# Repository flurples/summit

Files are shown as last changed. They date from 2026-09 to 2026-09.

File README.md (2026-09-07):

# summit
a gummy o-ring mount, mx compatible, symmetric hhkb

front-cover
build video: https://youtu.be/qhuydgdiscI

## specifications
- bakeneko/unikorn style gummy o-ring mount with hhkb exclusive design
- typing angle: 7.5°
- ekh: 23.6 mm
- supported layout:
layout-options

## you will need
- 1x case
- 1x weight-internal
- 1x weight-external
- 1x plate
- 1x pcb
- 1x unified daughterboard s1 (be sure to get a double sided molex cable)
- 1x gummy o-ring (I really like graveshift o-rings but any o-rings designed to work with a 60% will do)
- 6x m3 x 6mm flat head hex screws
- 4x 7.9mm diameter rubber feet (I use 3m sj5302)

## build notes
- all holes should be tapped with m3 threads.
- weight-internal and weight-external are designed to be cnc'd or laser cut from 1.6mm sheet metal, which can potentially save on manufacturing costs compared to typical 3d cnc'd weights.
- as with any gummy o-ring mount, plateless is not recommended.

## disclaimer
I do not sell any products, and I am not affiliated with any vendors who claim to sell my designs. if you choose to support these vendors, I am not responsible for any issues you may encounter with them.

## renders
frontv5
bottomv5brass
bottomv5ss
explodedv1-centered

## gallery
note: images are of an older version of the summit, with a different internal weight design
front-pom
front-striker

back
back-closeup
inside
inside-closeup
usbc

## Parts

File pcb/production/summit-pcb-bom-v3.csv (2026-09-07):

Comment | Designator | Footprint | LCSC Part Number
0.1uF | C1,C2,C3 | Capacitor_SMD:C_0805_2012Metric | C1711
10uF | C4 | Capacitor_SMD:C_0805_2012Metric | C17024
22pF | C5,C6 | Capacitor_SMD:C_0805_2012Metric | C1804
1uF | C7 | Capacitor_SMD:C_0805_2012Metric | C28323
SOD-123 | D1,D2,D3,D4,D5,D6,D7,D8,D9,D10,D11,D12,D13,D14,D15,D16,D17,D18,D19,D20,D21,D22,D23,D24,D25,D26,D27,D28,D29,D30,D31,D32,D33,D34,D35,D36,D37,D38,D39,D40,D41,D42,D43,D44,D45,D46,D47,D48,D49,D50,D51,D52,D53,D54,D55,D56,D57,D58,D59,D60,D61,D62 | Diode_SMD:D_SOD-123 | C2099
500mA | F1 | Fuse:Fuse_1206_3216Metric | C369160
Conn_01x04 | J1 | Connector_Molex:Molex_Pico-EZmate_78171-0004_1x04-1MP_P1.20mm_Vertical | C2829871
22 | R1,R2 | Resistor_SMD:R_0805_2012Metric | C17561
10k | R3,R4 | Resistor_SMD:R_0805_2012Metric | C17414
SW_Push | SW1 | random-keyboard-parts:SKQG-1155865 | C5140332
ATmega32U4-MU | U1 | Package_DFN_QFN:QFN-44-1EP_7x7mm_P0.5mm_EP5.2x5.2mm | C112161
16MHz | Y1 | Crystal:Crystal_SMD_3225-4Pin_3.2x2.5mm | C13738

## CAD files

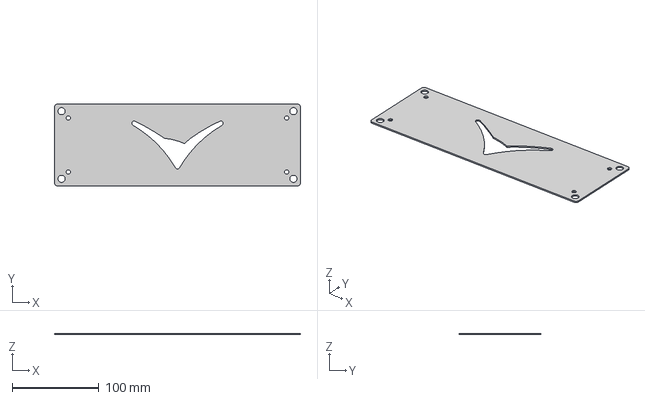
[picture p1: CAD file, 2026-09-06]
case/step/summit-weight-external.step
284.0 x 94.4 x 1.60 mm

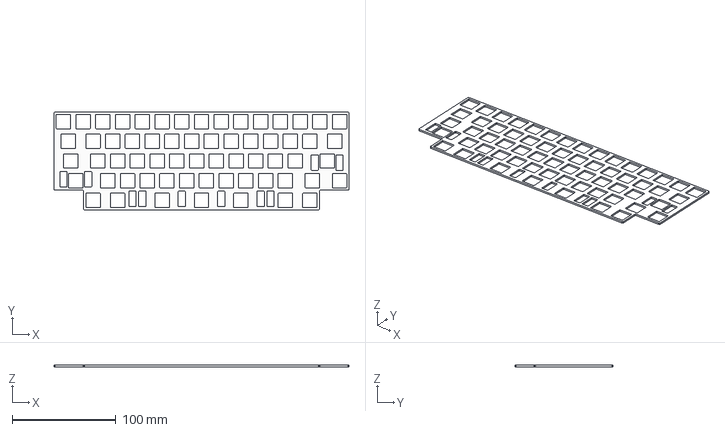
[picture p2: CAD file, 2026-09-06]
plate/step/summit-plate.step
285.0 x 94.4 x 1.60 mm

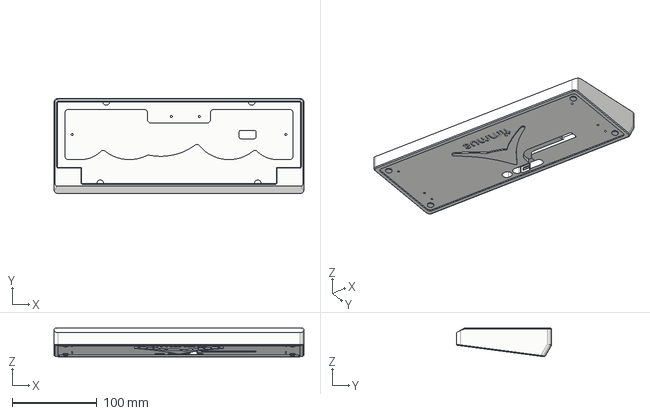
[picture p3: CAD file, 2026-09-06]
case/step/summit-case.step
294.8 x 112.2 x 33.6 mm

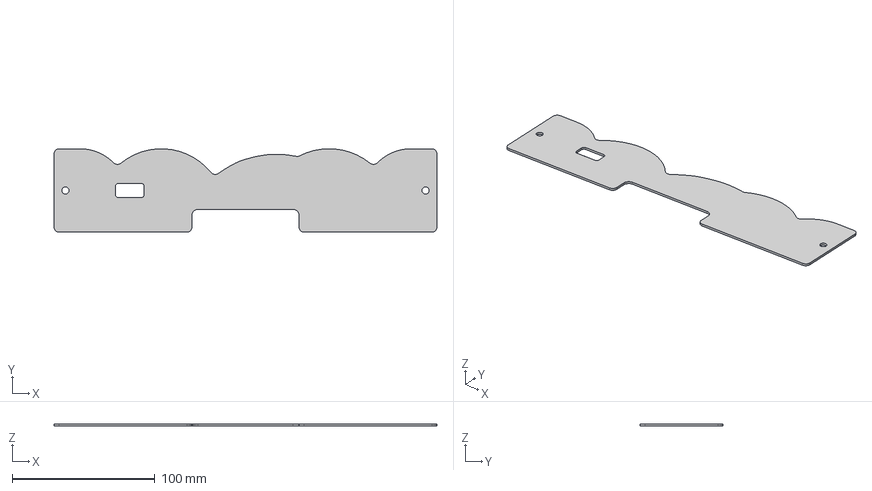
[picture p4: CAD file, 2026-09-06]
case/step/summit-weight-internal.step
268.0 x 58.4 x 1.60 mm

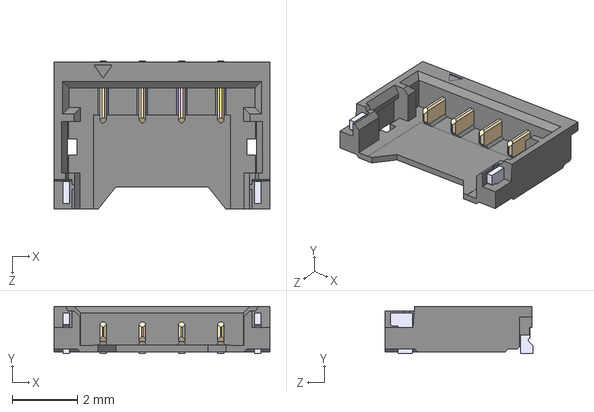
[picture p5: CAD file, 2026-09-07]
pcb/extra/0781710004.step
6.60 x 1.45 x 4.53 mm

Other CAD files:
case/dxf/summit-weight-external.dxf
case/dxf/summit-weight-internal.dxf
plate/dxf/summit-plate.dxf

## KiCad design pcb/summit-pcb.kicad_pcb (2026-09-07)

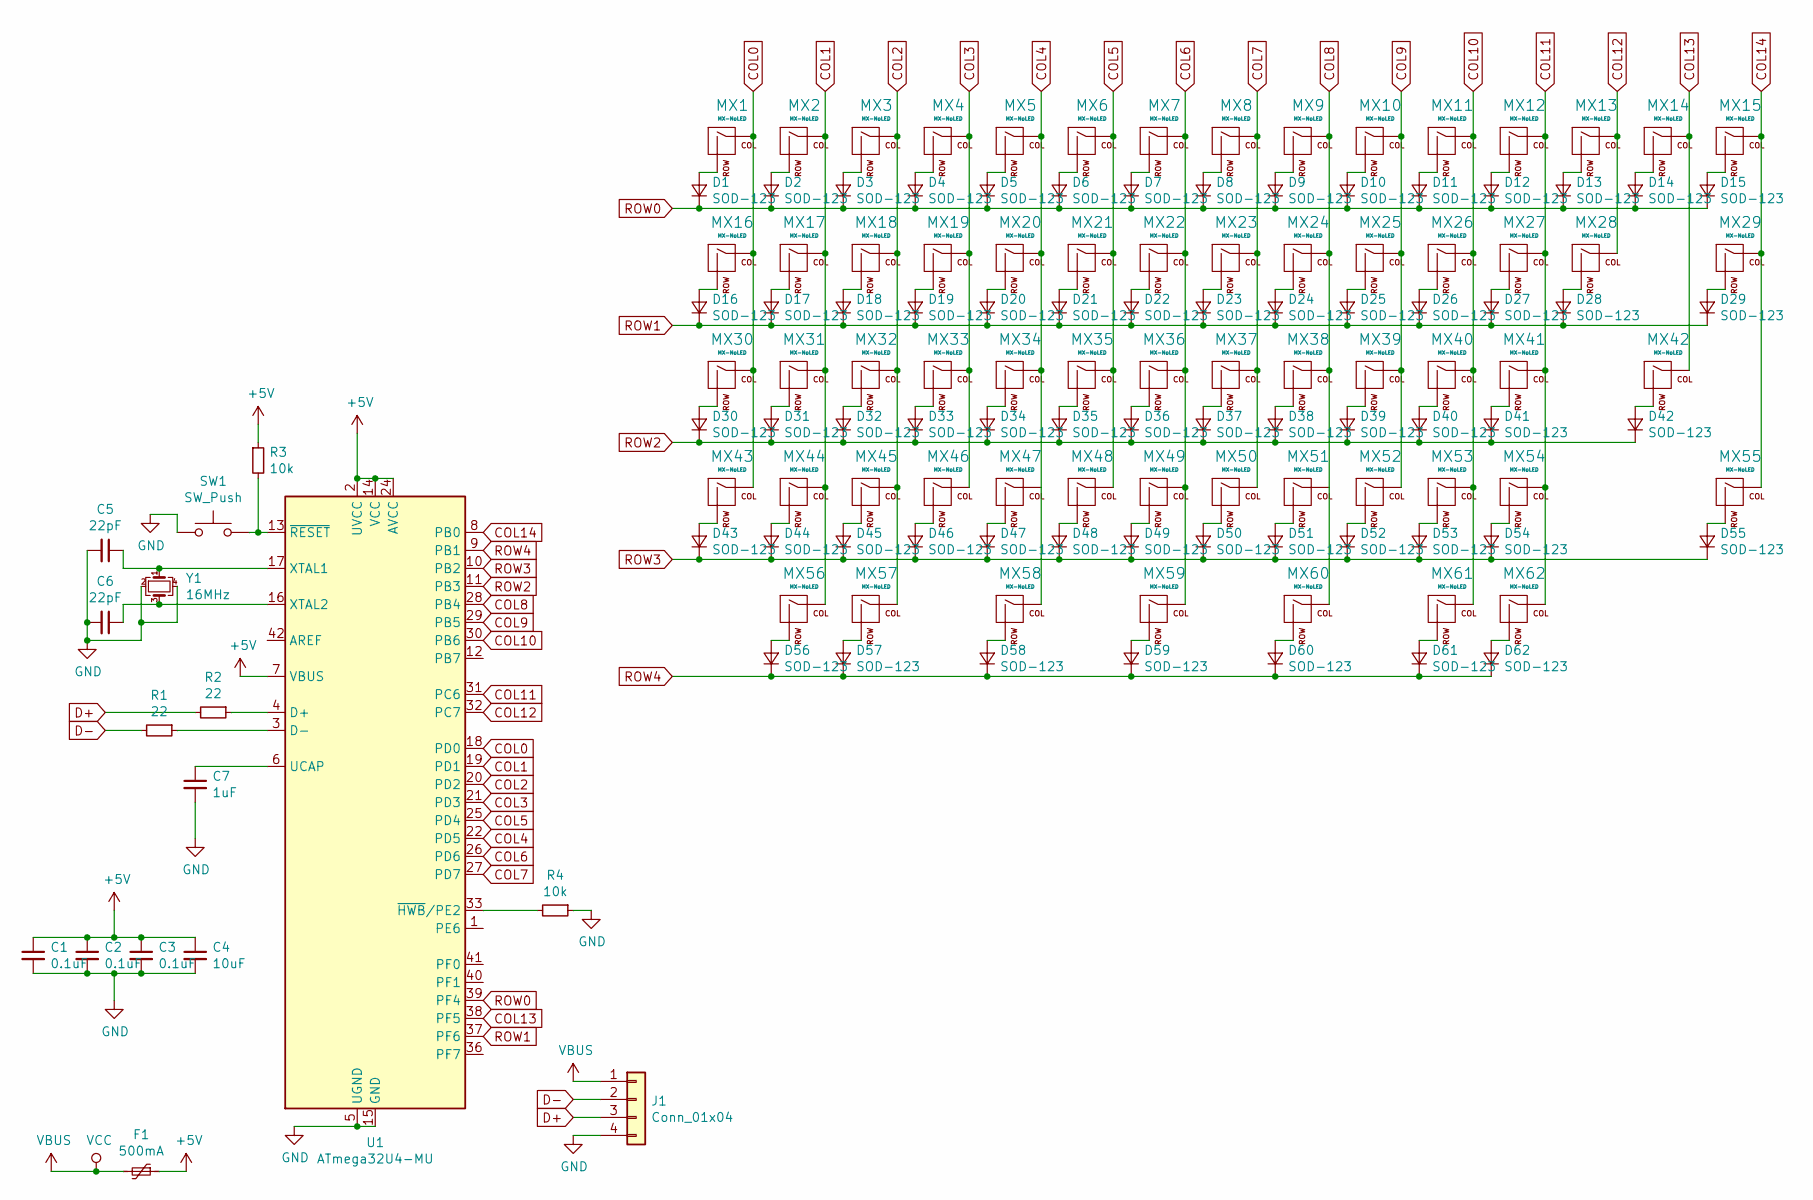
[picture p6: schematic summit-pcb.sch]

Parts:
C1, C2, C3: 0.1uF; C_0805_2012Metric
C4: 10uF; C_0805_2012Metric
C5, C6: 22pF; C_0805_2012Metric
C7: 1uF; C_0805_2012Metric
D1, D2, D3, D4, D5, D6, D7, D8, D9, D10, D11, D12, D13, D14, D15, D16, D17, D18, D19, D20, D21, D22, D23, D24, D25, D26, D27, D28, D29, D30, D31, D32, D33, D34, D35, D36, D37, D38, D39, D40, D41, D42, D43, D44, D45, D46, D47, D48, D49, D50, D51, D52, D53, D54, D55, D56, D57, D58, D59, D60, D61, D62: SOD-123; D_SOD-123
F1: 500mA; Fuse_1206_3216Metric
J1: Conn_01x04; Molex_Pico-EZmate_78171-0004_1x04-1MP_P1.20mm_Vertical
MX1, MX2, MX3, MX4, MX5, MX6, MX7, MX8, MX9, MX10, MX11, MX12, MX13, MX14, MX15, MX17, MX18, MX19, MX20, MX21, MX22, MX23, MX24, MX25, MX26, MX27, MX28, MX31, MX32, MX33, MX34, MX35, MX36, MX37, MX38, MX39, MX40, MX41, MX44, MX45, MX46, MX47, MX48, MX49, MX50, MX51, MX52, MX53, MX55, MX56, MX62: MX-NoLED; MXOnly-1U-NoLED
MX16, MX29, MX57, MX61: MX-NoLED; MXOnly-1.5U-NoLED
MX30, MX54: MX-NoLED; MXOnly-1.75U-NoLED
MX42: MX-NoLED; MXOnly-2.25U-NoLED
MX43: MX-NoLED; MXOnly-2.25U-ReversedStabilizers-NoLED
MX58, MX60: MX-NoLED; MXOnly-3U-ReversedStabilizers-NoLED
MX59: MX-NoLED; MX-10U-ReversedStabilizers-NoLED
R1, R2: 22; R_0805_2012Metric
R3, R4: 10k; R_0805_2012Metric
SW1: SW_Push; SKQG-1155865
U1: ATmega32U4-MU; QFN-44-1EP_7x7mm_P0.5mm_EP5.2x5.2mm
Y1: 16MHz; Crystal_SMD_3225-4Pin_3.2x2.5mm

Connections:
+5V: C1.1, C2.1, C3.1, C4.1, F1.1, R3.1, U1.2 (UVCC), U1.7 (VBUS), U1.14 (VCC), U1.24 (AVCC), U1.34 (VCC), U1.44 (AVCC)
COL0: MX1.1 (COL), MX16.1 (COL), MX30.1 (COL), MX43.1 (COL), U1.18 (PD0)
COL1: MX2.1 (COL), MX17.1 (COL), MX31.1 (COL), MX44.1 (COL), MX56.1 (COL), U1.19 (PD1)
COL2: MX3.1 (COL), MX18.1 (COL), MX32.1 (COL), MX45.1 (COL), MX57.1 (COL), U1.20 (PD2)
COL3: MX4.1 (COL), MX19.1 (COL), MX33.1 (COL), MX46.1 (COL), U1.21 (PD3)
COL4: MX5.1 (COL), MX20.1 (COL), MX34.1 (COL), MX47.1 (COL), MX58.1 (COL), U1.22 (PD5)
COL5: MX6.1 (COL), MX21.1 (COL), MX35.1 (COL), MX48.1 (COL), U1.25 (PD4)
COL6: MX7.1 (COL), MX22.1 (COL), MX36.1 (COL), MX49.1 (COL), MX59.1 (COL), U1.26 (PD6)
COL7: MX8.1 (COL), MX23.1 (COL), MX37.1 (COL), MX50.1 (COL), U1.27 (PD7)
COL8: MX9.1 (COL), MX24.1 (COL), MX38.1 (COL), MX51.1 (COL), MX60.1 (COL), U1.28 (PB4)
COL9: MX10.1 (COL), MX25.1 (COL), MX39.1 (COL), MX52.1 (COL), U1.29 (PB5)
COL10: MX11.1 (COL), MX26.1 (COL), MX40.1 (COL), MX53.1 (COL), MX61.1 (COL), U1.30 (PB6)
COL11: MX12.1 (COL), MX27.1 (COL), MX41.1 (COL), MX54.1 (COL), MX62.1 (COL), U1.31 (PC6)
COL12: MX13.1 (COL), MX28.1 (COL), U1.32 (PC7)
COL13: MX14.1 (COL), MX42.1 (COL), U1.38 (PF5)
COL14: MX15.1 (COL), MX29.1 (COL), MX55.1 (COL), U1.8 (PB0)
D+: J1.3, R2.2
D-: J1.2, R1.2
GND: C1.2, C2.2, C3.2, C4.2, C5.2, C6.2, C7.2, J1.4, R4.1, SW1.1, U1.5 (UGND), U1.15 (GND), U1.23 (GND), U1.35 (GND), U1.43 (GND), U1.45 (GND), Y1.2, Y1.4
unnamed: C5.1, U1.17 (XTAL1), Y1.1
unnamed: C6.1, U1.16 (XTAL2), Y1.3
unnamed: C7.1, U1.6 (UCAP)
unnamed: D1.2 (A), MX1.2 (ROW)
unnamed: D2.2 (A), MX2.2 (ROW)
unnamed: D3.2 (A), MX3.2 (ROW)
unnamed: D4.2 (A), MX4.2 (ROW)
unnamed: D5.2 (A), MX5.2 (ROW)
unnamed: D6.2 (A), MX6.2 (ROW)
unnamed: D7.2 (A), MX7.2 (ROW)
unnamed: D8.2 (A), MX8.2 (ROW)
unnamed: D9.2 (A), MX9.2 (ROW)
unnamed: D10.2 (A), MX10.2 (ROW)
unnamed: D11.2 (A), MX11.2 (ROW)
unnamed: D12.2 (A), MX12.2 (ROW)
unnamed: D13.2 (A), MX13.2 (ROW)
unnamed: D14.2 (A), MX14.2 (ROW)
unnamed: D15.2 (A), MX15.2 (ROW)
unnamed: D16.2 (A), MX16.2 (ROW)
unnamed: D17.2 (A), MX17.2 (ROW)
unnamed: D18.2 (A), MX18.2 (ROW)
unnamed: D19.2 (A), MX19.2 (ROW)
unnamed: D20.2 (A), MX20.2 (ROW)
unnamed: D21.2 (A), MX21.2 (ROW)
unnamed: D22.2 (A), MX22.2 (ROW)
unnamed: D23.2 (A), MX23.2 (ROW)
unnamed: D24.2 (A), MX24.2 (ROW)
unnamed: D25.2 (A), MX25.2 (ROW)
unnamed: D26.2 (A), MX26.2 (ROW)
unnamed: D27.2 (A), MX27.2 (ROW)
unnamed: D28.2 (A), MX28.2 (ROW)
unnamed: D29.2 (A), MX29.2 (ROW)
unnamed: D30.2 (A), MX30.2 (ROW)
unnamed: D31.2 (A), MX31.2 (ROW)
unnamed: D32.2 (A), MX32.2 (ROW)
unnamed: D33.2 (A), MX33.2 (ROW)
unnamed: D34.2 (A), MX34.2 (ROW)
unnamed: D35.2 (A), MX35.2 (ROW)
unnamed: D36.2 (A), MX36.2 (ROW)
unnamed: D37.2 (A), MX37.2 (ROW)
unnamed: D38.2 (A), MX38.2 (ROW)
unnamed: D39.2 (A), MX39.2 (ROW)
unnamed: D40.2 (A), MX40.2 (ROW)
unnamed: D41.2 (A), MX41.2 (ROW)
unnamed: D42.2 (A), MX42.2 (ROW)
unnamed: D43.2 (A), MX43.2 (ROW)
unnamed: D44.2 (A), MX44.2 (ROW)
unnamed: D45.2 (A), MX45.2 (ROW)
unnamed: D46.2 (A), MX46.2 (ROW)
unnamed: D47.2 (A), MX47.2 (ROW)
unnamed: D48.2 (A), MX48.2 (ROW)
unnamed: D49.2 (A), MX49.2 (ROW)
unnamed: D50.2 (A), MX50.2 (ROW)
unnamed: D51.2 (A), MX51.2 (ROW)
unnamed: D52.2 (A), MX52.2 (ROW)
unnamed: D53.2 (A), MX53.2 (ROW)
unnamed: D54.2 (A), MX54.2 (ROW)
unnamed: D55.2 (A), MX55.2 (ROW)
unnamed: D56.2 (A), MX56.2 (ROW)
unnamed: D57.2 (A), MX57.2 (ROW)
unnamed: D58.2 (A), MX58.2 (ROW)
unnamed: D59.2 (A), MX59.2 (ROW)
unnamed: D60.2 (A), MX60.2 (ROW)
unnamed: D61.2 (A), MX61.2 (ROW)
unnamed: D62.2 (A), MX62.2 (ROW)
unnamed: R1.1, U1.3 (D-)
unnamed: R2.1, U1.4 (D+)
unnamed: R3.2, SW1.2, U1.13 (~RESET)
unnamed: R4.2, U1.33 (~HWB~/PE2)
ROW0: D1.1 (K), D2.1 (K), D3.1 (K), D4.1 (K), D5.1 (K), D6.1 (K), D7.1 (K), D8.1 (K), D9.1 (K), D10.1 (K), D11.1 (K), D12.1 (K), D13.1 (K), D14.1 (K), D15.1 (K), U1.39 (PF4)
ROW1: D16.1 (K), D17.1 (K), D18.1 (K), D19.1 (K), D20.1 (K), D21.1 (K), D22.1 (K), D23.1 (K), D24.1 (K), D25.1 (K), D26.1 (K), D27.1 (K), D28.1 (K), D29.1 (K), U1.37 (PF6)
ROW2: D30.1 (K), D31.1 (K), D32.1 (K), D33.1 (K), D34.1 (K), D35.1 (K), D36.1 (K), D37.1 (K), D38.1 (K), D39.1 (K), D40.1 (K), D41.1 (K), D42.1 (K), U1.11 (PB3)
ROW3: D43.1 (K), D44.1 (K), D45.1 (K), D46.1 (K), D47.1 (K), D48.1 (K), D49.1 (K), D50.1 (K), D51.1 (K), D52.1 (K), D53.1 (K), D54.1 (K), D55.1 (K), U1.10 (PB2)
ROW4: D56.1 (K), D57.1 (K), D58.1 (K), D59.1 (K), D60.1 (K), D61.1 (K), D62.1 (K), U1.9 (PB1)
VBUS: F1.2, J1.1

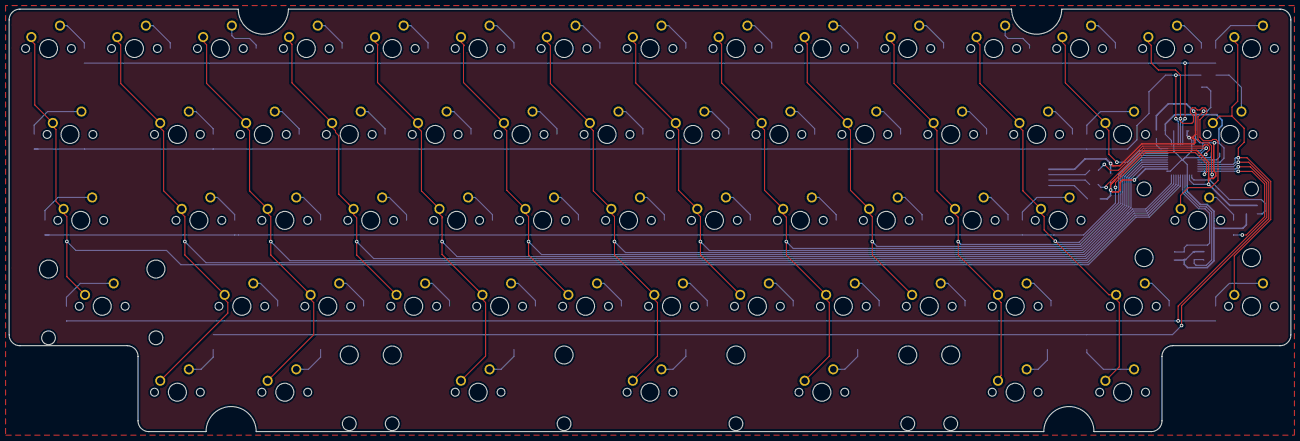
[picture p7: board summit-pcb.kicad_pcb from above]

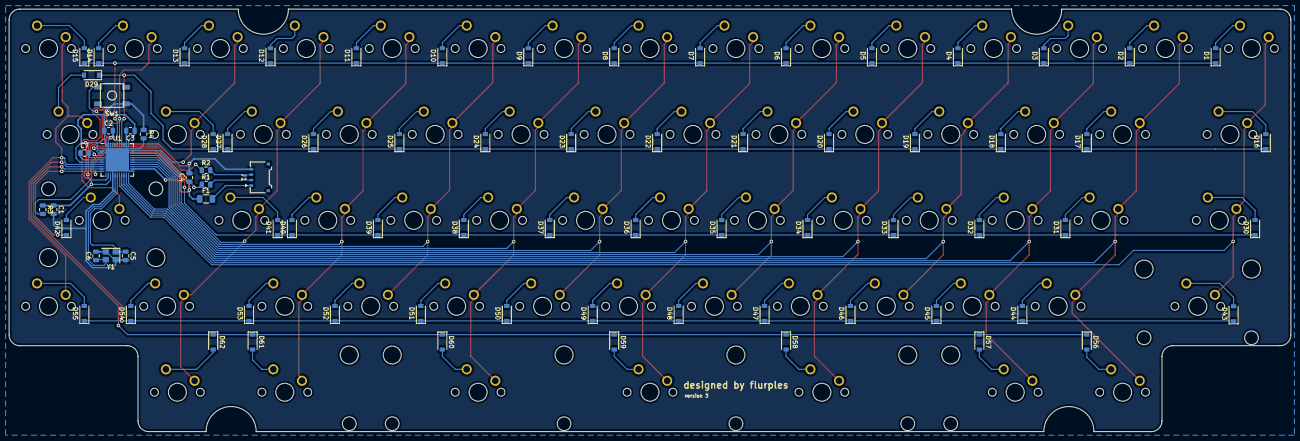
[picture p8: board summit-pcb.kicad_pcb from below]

Board: 2 copper layers, 284.2 x 93.7 mm, 140 parts (78 on the bottom side), 94 nets.

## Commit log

2026-09-06 add case and plate files
    [summit-case.step, summit-plate.dxf, summit-plate.step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]
2026-09-07 add pcb files
    [0781710004.step, summit-pcb-bom-v3.csv, summit-pcb.kicad_pcb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]
